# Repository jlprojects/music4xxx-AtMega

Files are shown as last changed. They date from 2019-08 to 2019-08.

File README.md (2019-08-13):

# music4xxx
## Hybrid Music 4000 - Midi adapter 

This is an adapter to allow a MIDI keyboard (or other MIDI device) to appear to the Hybrid Music System as a Hybrid Music4000 keyboard. 

The original Music4000 is a fully polyphonic four octave keyboard which connects to the BBC Microcomputer's user port. The keys are only switched, so there is no velocity or aftertouch. However these can be added after the fact in the Music5000 software.

The adapter takes Midi Note-On and Note-Off events and uses eight shift registers to replicate the original Music4000 keyboard matrix. The shift registers are latched automatically by the host BBC Micro's user port. It uses all through-hole parts, so is easy to build, and as the BBC Micro's userport is handled using hardware, the code on the microcontroller is simplified.. The ATMega328 microcontroller is programmed using the Arduino environment. A simple 3d printed enclosure is provided.

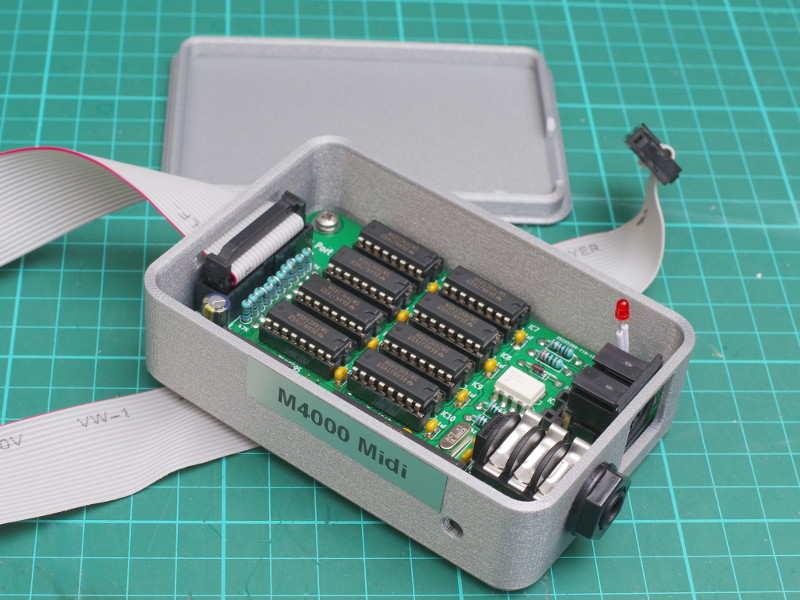
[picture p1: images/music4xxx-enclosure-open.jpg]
music4xxx boxed


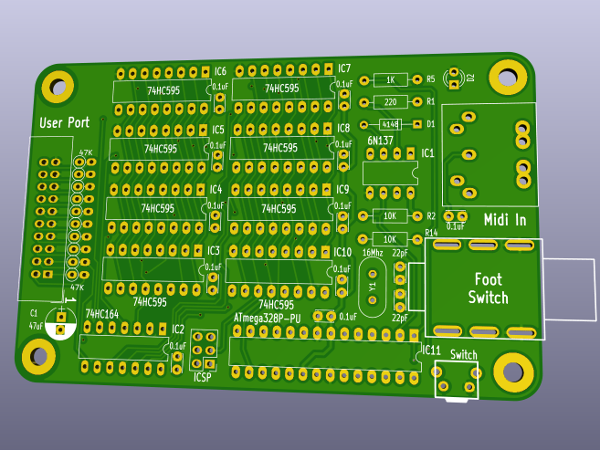
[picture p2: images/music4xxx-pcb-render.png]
music4xxx PCB render


## Resources

* Retro-kit's archive of information of the original Music 4000 keyboard, including manuals and brochures: https://www.retro-kit.co.uk/page.cfm/content/Hybrid-Music-4000-Keyboard/

* Here's the Stardot thread about this project: https://stardot.org.uk/forums/viewtopic.php?f=3&t=16895

* The Stardot 8bit hardware forum often has posts about the Hybrid Music system: https://stardot.org.uk/forums/viewforum.php?f=3

## Other options

There are a couple of independently developed alternatives:

* Hideaway Studio's commercially available adapter: http://www.hideawaystudio.net/ details: https://stardot.org.uk/forums/viewtopic.php?f=3&t=16893

* Daniel J's open source STM32 and Blue Pill based solutions: Github: https://github.com/drdpj/MidiKeyboardBluePill Stardot thread: https://stardot.org.uk/forums/viewtopic.php?f=3&t=17146

## Licence

Unless otherwise marked, work in this repository is licenced under [Creative Commons Attribution-ShareAlike 4.0 International License](http://creativecommons.org/licenses/by-sa/4.0/)

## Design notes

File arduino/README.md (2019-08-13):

# music4xxx firmware
## Hybrid Music 4000 - Midi adapter 

This is an Arduino sketch for the m4000-Midi adapter.

The code is licenced under [Creative Commons Attribution-NonCommercial-ShareAlike](http://creativecommons.org/licenses/by-nc-sa/4.0/)

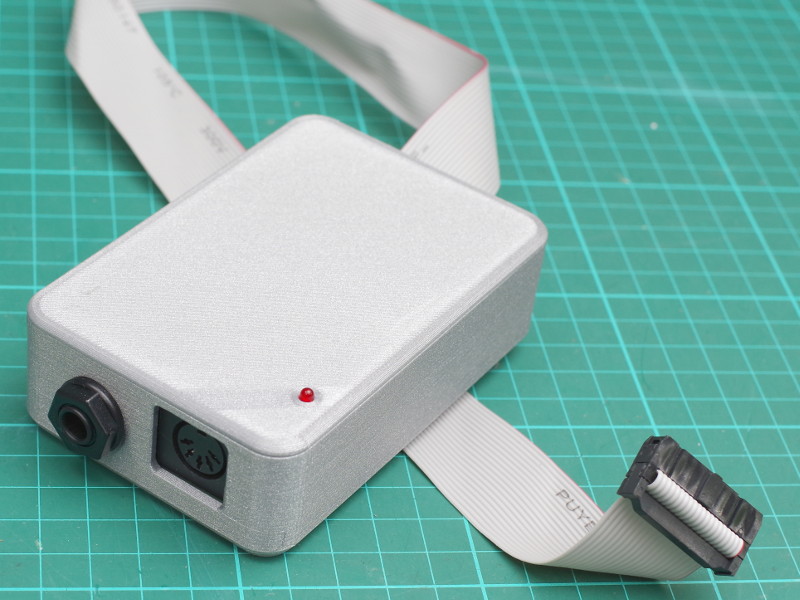
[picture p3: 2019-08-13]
images/music4xxx-enclosure-closed.jpg

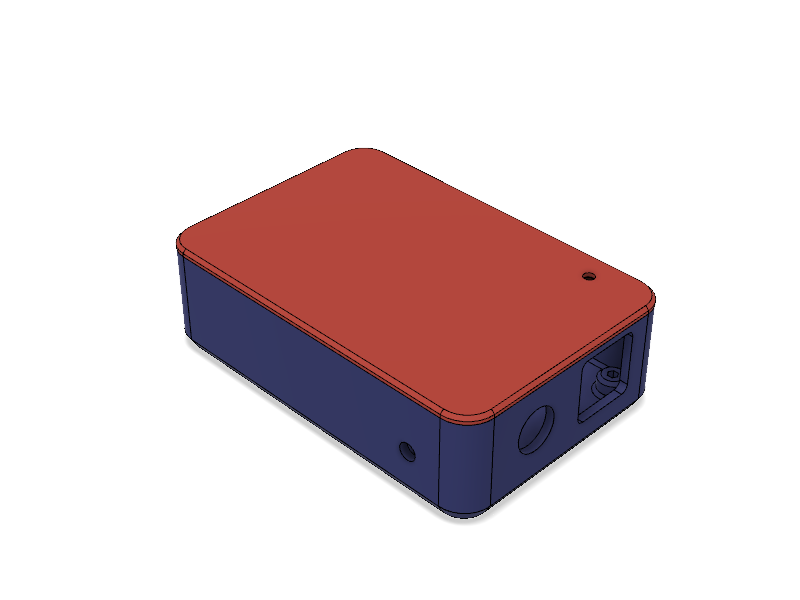
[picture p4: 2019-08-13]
enclosure/M4xxx-box.png

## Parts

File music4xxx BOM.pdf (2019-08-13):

music4xxx

## Music4xxx PCB BOM

Quantity Designation | Designator | Notes

Resistors
1 | 1K
| | R5
2 | 10K
10 | 47K

Capacitors
2 | 22pF | C13, C14 | Ceramic: 2.5mm lead pitch
11 | 0.1uF
1 | 47uF | C1 | Electrolytic 2.5mm lead pitch

Diodes
1 | 1N4148 | D1 | DO35
1 | PWR | D2 | 3mm LED

Integrated Circuits
1 | 6N137 | IC1 | Optocoupler
1 | ATmega328P-PU IC11 | Microcontroller
1 | 74HC164 | IC2 | Shift Register
8 | 74HC595 | IC3, IC4, IC5, IC6, IC7, IC8, IC9, IC10 Shift Register

IC Sockets
1 | 8 Way | 7.62mm wide
1 | 14 Way | 7.62mm wide
8 | 16 Way | 7.62mm wide

Sockets/headers
1 | MIDI DIN socket | J7
1 | ¼" jack socket | J3 | Like Neutrik-NMJ6HF-S for foot switch
1 | ICSP | P1 | 2x3 0.1" pin header for programming
1 | 20pin IDC socket J2 | 2x10way 0.1" for userport cable

Misc
1 | 16Mhs | Y1 | Crystal HC49 Through hole
1 | Pushbutton | SW1 | 7mm right-angle tactile switch
1 | 20way IDC cable n/a
2 | 20 way IDC plugs n/a | For userport connection

Standard 1% metal film through hole resistors
R2, R14
R3, R4, R6, R7, R8, R9, R10, R11, R12, R13

C2,C3, C4, C5, C6, C7, C8, C9, C10, C11, C12

Ceramic: 2.5mm lead pitch for decoupling

PCB mount 5 way din socket, 180°

Connect to Beeb’s user port. Allow 60cm.

For programming the microcontroller you will need an ICSP like Adafruit’s USBtinyISP (https://www.adafruit.com/product/46) or similar programmer compatible with Arduino

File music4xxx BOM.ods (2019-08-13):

Music4xxx PCB BOM
Quantity | Designation | Designator | Notes
Resistors
1 | 1K | R5 | Standard 1% metal film through hole resistors
2 | 10K | R2, R14
10 | 47K | R3, R4, R6, R7, R8, R9, R10, R11, R12, R13
Capacitors
2 | 22pF | C13, C14 | Ceramic: 2.5mm lead pitch
11 | 0.1uF | C2,C3, C4, C5, C6, C7, C8, C9, C10, C11, C12 | Ceramic: 2.5mm lead pitch for decoupling
1 | 47uF | C1 | Electrolytic 2.5mm lead pitch
Diodes
1 | 1N4148 | D1 | DO35
1 | PWR | D2 | 3mm LED
Integrated Circuits
1 | 6N137 | IC1 | Optocoupler
1 | ATmega328P-PU | IC11 | Microcontroller
1 | 74HC164 | IC2 | Shift Register
8 | 74HC595 | IC3, IC4, IC5, IC6, IC7, IC8, IC9, IC10 | Shift Register
IC Sockets
1 | 8 Way | 7.62mm wide
1 | 14 Way | 7.62mm wide
8 | 16 Way | 7.62mm wide
Sockets/headers
1 | MIDI DIN socket | J7 | PCB mount 5 way din socket, 180°
1 | ¼" jack socket | J3 | Like Neutrik-NMJ6HF-S for foot switch
1 | ICSP | P1 | 2x3 0.1" pin header for programming
1 | 20pin IDC socket | J2 | 2x10way 0.1" for userport cable
Misc
1 | 16Mhs | Y1 | Crystal HC49 Through hole
1 | Pushbutton | SW1 | 7mm right-angle tactile switch
1 | 20way IDC cable | n/a | Connect to Beeb’s user port. Allow 60cm.
2 | 20 way IDC plugs | n/a | For userport connection
For programming the microcontroller you will need an ICSP like Adafruit’s USBtinyISP or similar programmer compatible with Arduino (https://www.adafruit.com/product/46)

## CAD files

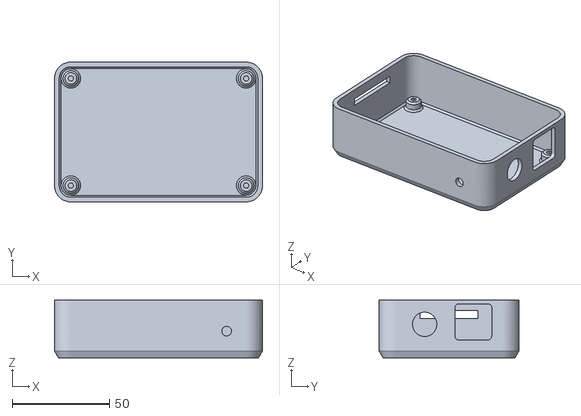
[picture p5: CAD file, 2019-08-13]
enclosure/M4xxx-ATMega-base.stl
106.8 x 71.8 x 29.6

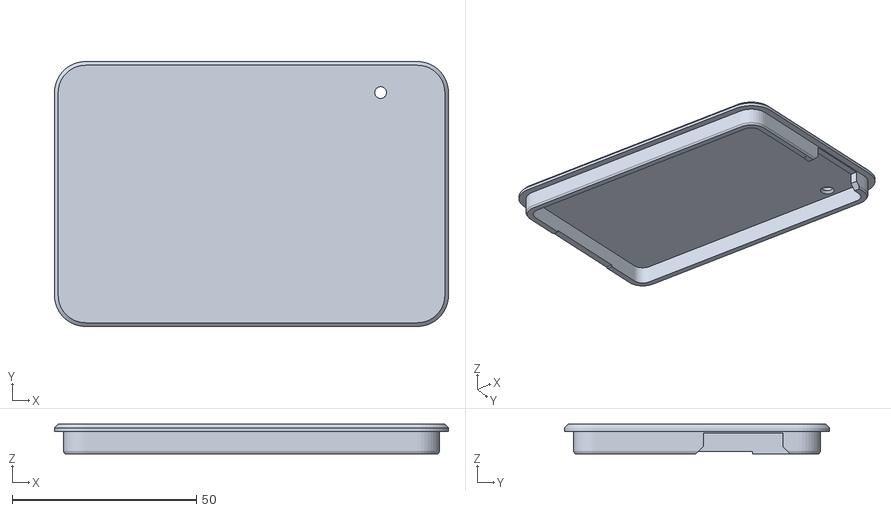
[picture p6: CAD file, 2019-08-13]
enclosure/M4xxx-ATMega-lid.stl
106.8 x 71.8 x 8.00

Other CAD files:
enclosure/M4xxxATMega.f3d

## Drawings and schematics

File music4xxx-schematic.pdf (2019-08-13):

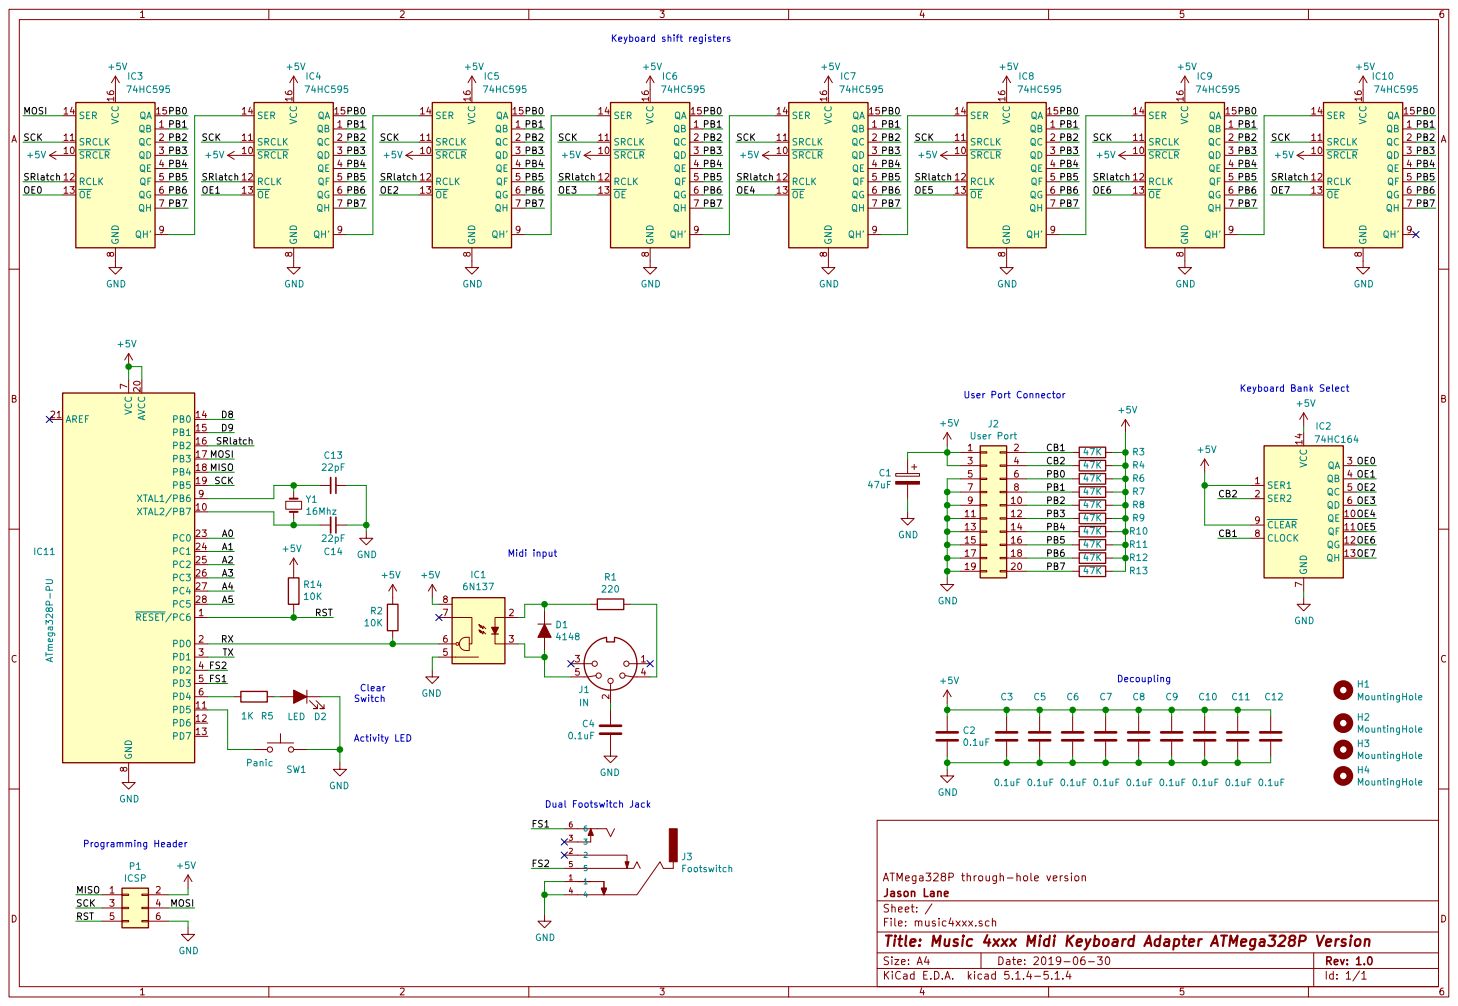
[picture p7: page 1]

9 | 10
11 | 12
13 | 14
15 | 16
17 | 18
19 | 20

Id: 1/1 Title: Music 4xxx Midi Keyboard Adapter ATMega328P Version

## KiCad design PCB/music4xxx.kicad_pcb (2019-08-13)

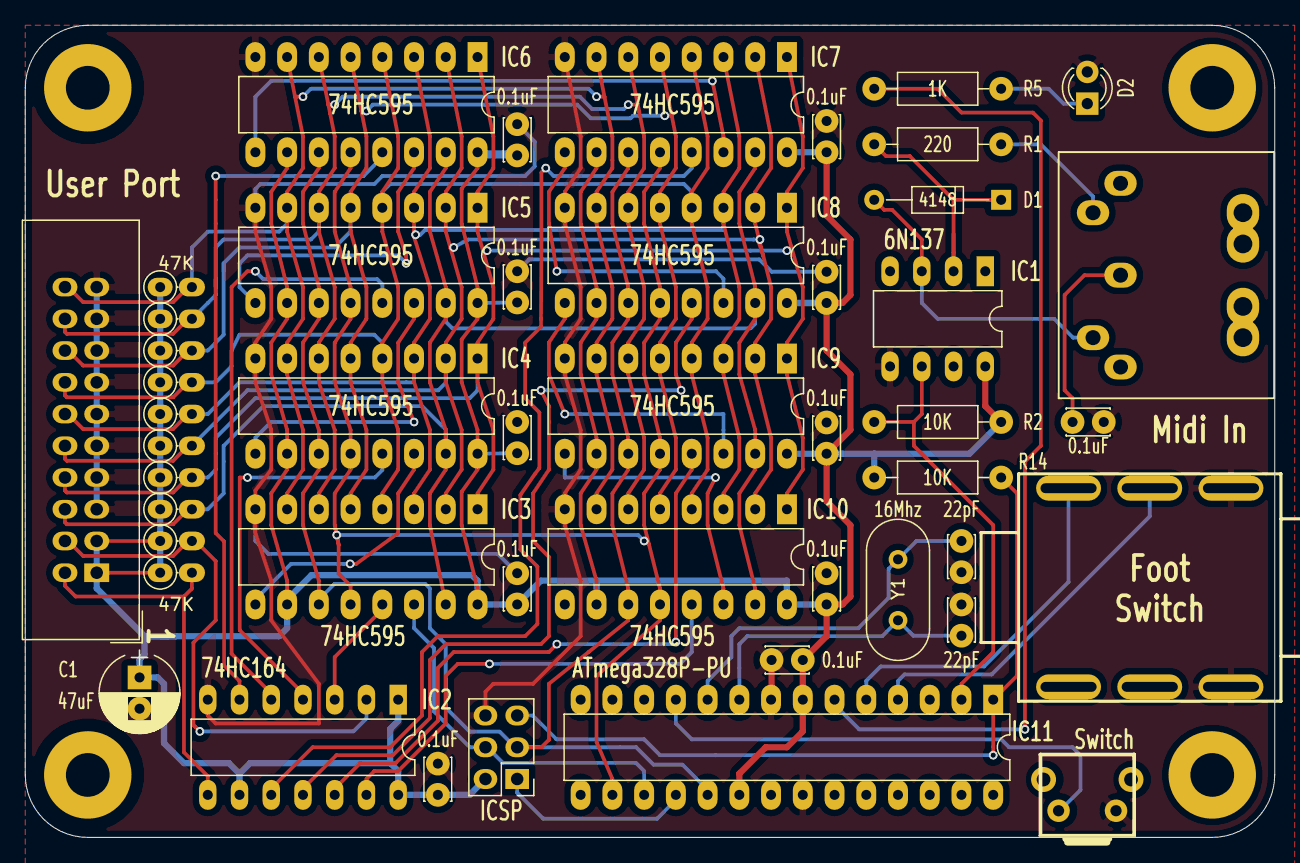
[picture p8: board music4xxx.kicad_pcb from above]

Board: 2 copper layers, 100.0 x 65.0 mm, 51 parts (0 on the bottom side), 44 nets.

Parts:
C1: 47uF; CP_Radial_D6.3mm_P2.50mm
C2, C3, C4, C5, C6, C7, C8, C9, C10, C11, C12: 0.1uF; C_Disc_D3.4mm_W2.1mm_P2.50mm
C13, C14: 22pF; C_Disc_D3.4mm_W2.1mm_P2.50mm
D1: 4148; D_DO-35_SOD27_P10.16mm_Horizontal
D2: LED; LED_D3.0mm
H1, H2, H3, H4: MountingHole; MountingHole_3.5mm_Pad
IC1: 6N137; DIP-8_W7.62mm_LongPads
IC2: 74HC164; DIP-14_W7.62mm_LongPads
IC3, IC4, IC5, IC6, IC7, IC8, IC9, IC10: 74HC595; DIP-16_W7.62mm_LongPads
IC11: ATmega328P-PU; DIP-28_W7.62mm
J1: IN; din_5_pcb_mount
J2: User Port; IDC-Header_2x10_Pitch2.54mm_Straight
J3: Footswitch; Neutrik-NMJ6HF-S
P1: ICSP; Pin_Header_Straight_2x03_Pitch2.54mm
R1: 220; R_Axial_DIN0207_L6.3mm_D2.5mm_P10.16mm_Horizontal
R2, R14: 10K; R_Axial_DIN0207_L6.3mm_D2.5mm_P10.16mm_Horizontal
R3, R4, R6, R7, R8, R9, R10, R11, R12, R13: 47K; R_Axial_DIN0207_L6.3mm_D2.5mm_P2.54mm_Vertical
R5: 1K; R_Axial_DIN0207_L6.3mm_D2.5mm_P10.16mm_Horizontal
SW1: Panic; VerticalTactSwitch
Y1: 16Mhz; Crystal_HC49-U_Vertical

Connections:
+5V: C1.1, C2.1, C3.1, C5.1, C6.1, C7.1, C8.1, C9.1, C10.1, C11.1, C12.1, IC1.8, IC2.1, IC2.9, IC2.14, IC3.10, IC3.16, IC4.10, IC4.16, IC5.10, IC5.16, IC6.10, IC6.16, IC7.10, IC7.16, IC8.10, IC8.16, IC9.10, IC9.16, IC10.10, IC10.16, IC11.7, IC11.20, J2.1, J2.3, P1.2, R2.2, R3.1, R4.1, R6.1, R7.1, R8.1, R9.1, R10.1, R11.1, R12.1, R13.1, R14.2
/CB1: IC2.8, J2.2, R3.2
/CB2: IC2.2, J2.4, R4.2
/FS1: IC11.5, J3.6
/FS2: IC11.4, J3.5
/MISO: IC11.18, P1.1
/MOSI: IC3.14, IC11.17, P1.4
/OE0: IC2.3, IC3.13
/OE1: IC2.4, IC4.13
/OE2: IC2.5, IC5.13
/OE3: IC2.6, IC6.13
/OE4: IC2.10, IC7.13
/OE5: IC2.11, IC8.13
/OE6: IC2.12, IC9.13
/OE7: IC2.13, IC10.13
/PB0: IC3.15, IC4.15, IC5.15, IC6.15, IC7.15, IC8.15, IC9.15, IC10.15, J2.6, R6.2
/PB1: IC3.1, IC4.1, IC5.1, IC6.1, IC7.1, IC8.1, IC9.1, IC10.1, J2.8, R7.2
/PB2: IC3.2, IC4.2, IC5.2, IC6.2, IC7.2, IC8.2, IC9.2, IC10.2, J2.10, R8.2
/PB3: IC3.3, IC4.3, IC5.3, IC6.3, IC7.3, IC8.3, IC9.3, IC10.3, J2.12, R9.2
/PB4: IC3.4, IC4.4, IC5.4, IC6.4, IC7.4, IC8.4, IC9.4, IC10.4, J2.14, R10.2
/PB5: IC3.5, IC4.5, IC5.5, IC6.5, IC7.5, IC8.5, IC9.5, IC10.5, J2.16, R11.2
/PB6: IC3.6, IC4.6, IC5.6, IC6.6, IC7.6, IC8.6, IC9.6, IC10.6, J2.18, R12.2
/PB7: IC3.7, IC4.7, IC5.7, IC6.7, IC7.7, IC8.7, IC9.7, IC10.7, J2.20, R13.2
/RST: IC11.1, P1.5, R14.1
/RX: IC1.6, IC11.2, R2.1
/SCK: IC3.11, IC4.11, IC5.11, IC6.11, IC7.11, IC8.11, IC9.11, IC10.11, IC11.19, P1.3
/SRlatch: IC3.12, IC4.12, IC5.12, IC6.12, IC7.12, IC8.12, IC9.12, IC10.12, IC11.16
GND: C1.2, C2.2, C3.2, C4.2, C5.2, C6.2, C7.2, C8.2, C9.2, C10.2, C11.2, C12.2, C13.1, C14.1, D2.1, IC1.5, IC2.7, IC3.8, IC4.8, IC5.8, IC6.8, IC7.8, IC8.8, IC9.8, IC10.8, IC11.8, IC11.22, J2.5, J2.7, J2.9, J2.11, J2.13, J2.15, J2.17, J2.19, J3.1, J3.4, P1.6, SW1.1
unnamed: C4.1, J1.2
unnamed: C13.2, IC11.9, Y1.1
unnamed: C14.2, IC11.10, Y1.2
unnamed: D1.1, IC1.2, R1.1
unnamed: D1.2, IC1.3, J1.5
unnamed: D2.2, R5.1
unnamed: IC3.9, IC4.14
unnamed: IC4.9, IC5.14
unnamed: IC5.9, IC6.14
unnamed: IC6.9, IC7.14
unnamed: IC7.9, IC8.14
unnamed: IC8.9, IC9.14
unnamed: IC9.9, IC10.14
unnamed: IC11.6, R5.2
unnamed: IC11.11, SW1.2
unnamed: J1.4, R1.2

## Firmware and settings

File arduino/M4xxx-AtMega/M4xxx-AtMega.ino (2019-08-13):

/*
 * Music 4000 Midi Keyboard Adapter
 * For the BBC Micro computer
 * ATMega328P version
 * 
 *  Copyright Jason Lane 2019
 *
 *  This work is licensed under the Creative Commons Attribution-NonCommercial-ShareAlike 4.0 International License. 
 *  To view a copy of this license, visit http://creativecommons.org/licenses/by-nc-sa/4.0/ or send a letter to 
 *  Creative Commons, PO Box 1866, Mountain View, CA 94042, USA.
 * 
 */
#include <SPI.h>
#include <elapsedMillis.h>
#include <EEPROM.h>
#include "pintimer.h"

//#define DEBUG 1

// Pins
#define LEDpin 4
#define SWpin 5
#define FS1pin 3
#define FS2pin 2
#define SRlatch 10
#define SRdata 11
#define SRclk 13
#define MIDIin 0
#define MIDI_MIN_NOTE 36
#define MIDI_MAX_NOTE 84
#define MIDI_NOTEON 0x90
#define MIDI_NOTEOFF 0x80
#define MIDI_CTRLCHG 0xB0

uint8_t noteOnCmd  = 0x90;
uint8_t noteOffCmd = 0x80;
uint8_t controlChangeCmd = 0xB0;
uint8_t allNotesOffCmd = 0x7B;

#define CHANNEL_ADDR 1
volatile uint8_t midiChannel = 0;
boolean setMIDIchan = false;

PinTimer led(LEDpin);
uint8_t KB[8] = {0xFF, 0xFF, 0xFF, 0xFF, 0xFF, 0xFF, 0xFF, 0xFF };
bool kbChanged;

void updateKB() {
  // Send current KB status to shift registers
  SPI.beginTransaction( SPISettings(10000000, MSBFIRST, SPI_MODE0) );
  digitalWrite( SRlatch, LOW );
  for (uint8_t i=0; i<8; i++)  SPI.transfer( KB[i] );
  digitalWrite( SRlatch, HIGH );
  SPI.endTransaction();
}

void updateLED() {
  uint8_t i = 0;
  bool led = false;
  for (i=1; i<8; i++) {
    if (KB[i] != 0xFF) led = true;
  }
  digitalWrite( LEDpin, led );
}

void keyOff( uint8_t k ) {
  uint8_t kblock = k / 8;
  uint8_t kbit = k % 8;
  bitSet( KB[7-kblock], kbit );
  kbChanged = true;
}

void keyOn( uint8_t k ) {
  uint8_t kblock = k / 8;
  uint8_t kbit = k % 8;
  bitClear( KB[7-kblock], kbit );
  kbChanged = true;
}
 
void clearNotes() {
  for (uint8_t i=0; i<8; i++) KB[i] = 0xFF;
}

void parseMIDI() {
  // Call when serial data is available
  static uint8_t state=0;
  static uint8_t cmd=0;
  static uint8_t note=0;
  static uint8_t vel=0;
  uint8_t m = Serial.read();
  if (m>=0x80 && m<=0xEF) {
    // Voice Category Status
    cmd = m;
    state = 0; 
  } else if (m>=0xF0 && m<=0xF7) {
    // System Common Status
    cmd = 0;
    state = 0;
  }
  if (cmd>0) {
    switch (state) {
      case 0:
        // cmd read
        if (cmd==MIDI_NOTEON) {
          state = 1;
        } else if (cmd==MIDI_NOTEOFF) {
          state = 3;
        } else if (cmd==MIDI_CTRLCHG) {
          state = 5;
        } else {
          // Not recognised command so reset
          cmd = 0;
        }
        break;
      case 1:
        // read note
        note = m;
        state=2;
        break;
      case 2:
        // read vel
        vel = m;
        state = 1;
        if (note>=MIDI_MIN_NOTE && note <=MIDI_MAX_NOTE) {
          // Only use range available for keyboard
          if (vel>0) {
            // Note on
            keyOn(note-MIDI_MIN_NOTE);
          } else {
            // Note off
            keyOff(note-MIDI_MIN_NOTE);
          }
        }
      break;
      case 3:
        // Note Off read note
        note = m;
        state = 4;
      break;
      case 4:
        // Note Off read vel
        vel = m;
        keyOff(note-MIDI_MIN_NOTE);        
        state = 3;
      break;
      case 5:
        // Control change
        if (m>=0x7B && m<=0x7F) {
          // Clear all notes
          clearNotes();
        }
        state = 0;
      break;
    }
  }
}

void updateFootswitch() {
  // Check footswitch status every 40mS
  static elapsedMillis timer = 0;
  if (timer<40) return;
  timer = 0;
  static bool FS1status = digitalRead(FS1pin);
  static bool FS2status = digitalRead(FS2pin);
  bool FS1 = digitalRead(FS1pin);
  bool FS2 = digitalRead(FS2pin);
  if (FS1 != FS1status) {
    FS1status = FS1;
    if (!FS1) keyOn(63); else keyOff(63);
  }
  if (FS2 != FS2status) {
    FS2status = FS2;
    if (!FS2) keyOn(62); else keyOff(62);
  }
}

uint8_t readMIDIchannel() {
  uint8_t chan = EEPROM.read(CHANNEL_ADDR);
  if (chan>=16) {
    chan=0;
  }
  noteOnCmd  = 0x90|chan;
  noteOffCmd = 0x80|chan;
  controlChangeCmd = 0xB0|midiChannel;
  return chan;
}


void writeMIDIchannel(uint8_t chan) {
  // Store the MIDI channel
  EEPROM.write(CHANNEL_ADDR,chan);
}

elapsedMillis btnTimer = 0;
void handleButton() {
  // State machine to handle setting the MIDI channel
  // Unpressed, button is HIGH.
  // Hold button down for 3 secs to enter channel set mode
  static uint8_t state = 0;
  switch (state) {
    case 0:
      // Wait for button to be pressed
      if (digitalRead(SWpin)==LOW) {
        btnTimer = 0;
        state = 1;
      }
      break;
    case 1:
      // Wait for release or button held > 4 seconds
      if (digitalRead(SWpin)==HIGH) {
        state = 0;
      } else if (btnTimer>4000) {
        // start MIDI set mode
        state = 2;
        setMIDIchan = true;
        btnTimer = 0;
        led.oscillate(250);
      }
      break;
    case 2: 
      // wait for timeout 
      if (btnTimer>10000 || !setMIDIchan) {
        setMIDIchan = false;
        state = 0;
        led.off();
      }
      break;
  } 
}

void setup() {
  led.on();
  digitalWrite( LEDpin, HIGH );
  Serial.begin(31250); // Start MIDI on hardware serial
  SPI.begin();
  pinMode( SRlatch, OUTPUT );
  digitalWrite( SRlatch,HIGH );
  pinMode( SWpin, INPUT_PULLUP );
  pinMode( FS1pin, INPUT_PULLUP );
  pinMode( FS2pin, INPUT_PULLUP );
  updateKB();
  if (digitalRead(SWpin)) {
    midiChannel = readMIDIchannel();
  } else {
    // reset channel to 0
    midiChannel = 0;
    writeMIDIchannel( midiChannel );
  }
  delay(500);
  led.off();
}

void loop() {
  // put your main code here, to run repeatedly:
  if (Serial.available()) {
    parseMIDI();
  }
  updateFootswitch();
  if (kbChanged) {
    updateKB();
    updateLED();
    kbChanged = false;
  }
  handleButton();

}

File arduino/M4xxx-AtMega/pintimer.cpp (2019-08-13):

/* 
 *  Simply handle pulsing and oscillating a digital pin
 *    
 *  Copyright Jason Lane 2017
 *
 *  This work is licensed under the Creative Commons Attribution-NonCommercial-ShareAlike 4.0 International License. 
 *  To view a copy of this license, visit http://creativecommons.org/licenses/by-nc-sa/4.0/ or send a letter to 
 *  Creative Commons, PO Box 1866, Mountain View, CA 94042, USA.
 * 
 */

#include <Arduino.h>

#include "pintimer.h"


PinTimer::PinTimer(uint8_t pin) {
  // Constructor
  _pin = pin;
  pinMode( _pin, OUTPUT );
  _state = 0;
  _status = LOW;
  digitalWrite( _pin, LOW );
}
  
void PinTimer::update() {
  // update the state machine every so often
  if (_updTime>PT_UPDATEMICROS) {
    _updTime = 0;
    switch( _state ) {
      case 1:
        // oscillate
        if (_timer >= _oscTime) {
          _timer = 0;
          _status = !_status;
          digitalWrite(_pin,_status);
        }
        break;
      case 2:
        // pulse
        if (_timer >= _pulseTime) {
          _status = LOW;
          digitalWrite(_pin,LOW);
          _state = _oldState;
        }
        break;
      case 3:
        // count flashes
        if (_timer >= _flashTime) {
          _timer = 0;
          _status = !_status;
          digitalWrite(_pin,_status);
          if (!_status) {
            _flashCount--;
            if (_flashCount==0) {
              _state = _oldState;
            }
          }
        }
        break;

    }
  }
}

void PinTimer::on() {
  // switch on pin
  _status = HIGH;
  digitalWrite( _pin, HIGH );
  _state = 0;
}

void PinTimer::off() {
  // switch off pin
  _status = LOW;
  digitalWrite( _pin, LOW );
  _state = 0;
}

void PinTimer::pulse( uint16_t time ) {
  // switches pin for on time
  if (_state !=2) {
    _oldState = _state;
    _state = 2;
    _status = HIGH;
    digitalWrite( _pin, HIGH );
  }
  _pulseTime = time;
  _timer = 0;
}

void PinTimer::oscillate( uint16_t time ) {
  // starts oscillating pin for time
  _status = HIGH;
  digitalWrite( _pin, HIGH );
  _state = 1;
  _oscTime = time;
  _timer = 0;
}

void PinTimer::oscillate( uint16_t time, uint8_t flashes ) {
  // starts oscillating pin for time
  if (_state !=3) {
    _oldState = _state;
    _status = HIGH;
    digitalWrite( _pin, HIGH );
    _state = 3;
    _flashCount = flashes;
    _flashTime = time;
    _timer = 0;
  }
}
